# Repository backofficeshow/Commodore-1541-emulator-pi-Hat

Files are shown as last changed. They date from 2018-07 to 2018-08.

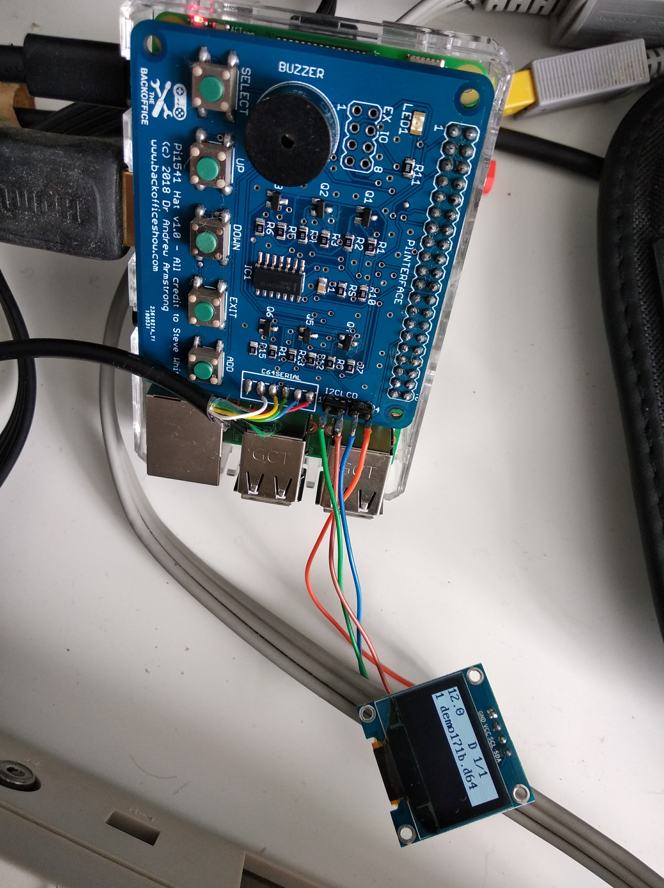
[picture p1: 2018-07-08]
Rob Taylor Test of V1.jpg

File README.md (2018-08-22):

# Commodore-1541-emulator-pi-Hat
Raspberry Pi Hat for Steve White's Excellent software emulated 1541

Feel free to use this design for your own personal use. If you want to use it in your commercial design please contact me first, this is a community supported design and to play fair its nice to be asked!

Steve White's excellent project:
https://cbm-pi1541.firebaseapp.com/

The video stream about this design:
https://youtu.be/9ZHAoGowLNE

The video stream about the build:
https://www.youtube.com/watch?v=_NtLqHfJCsg

Backofficeshow links:
https://www.youtube.com/backofficeshow
https://www.backofficeshow.com

Please feel free to ping me on twitter: @backofficeshow
or be a real superstar and consider buying me a coffee via Patreon: https://www.patreon.com/BackofficeShow

TODO:

Replace level shifting components with integrated circuit: http://www.ti.com/lit/ds/symlink/txb0108.pdf

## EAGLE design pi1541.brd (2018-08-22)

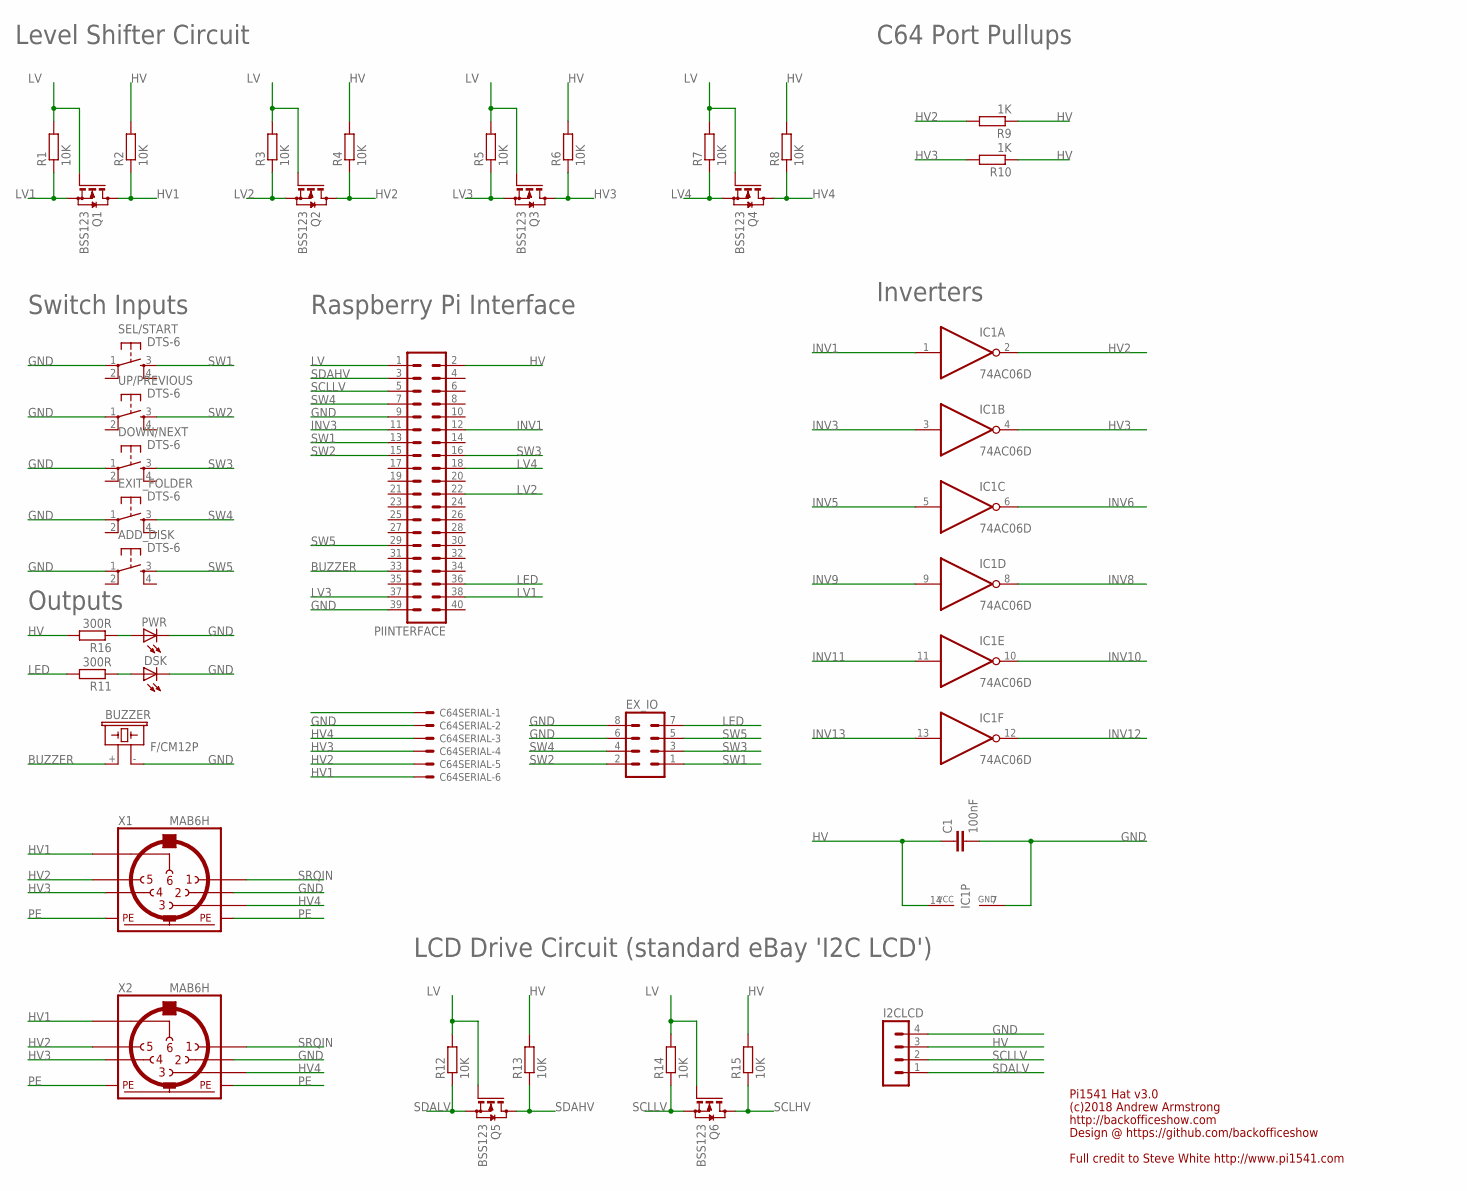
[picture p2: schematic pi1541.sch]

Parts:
ADD_DISK: DTS-6
BUZZER: F/CM12P
C1: 100nF; C0805
C64SERIAL: 22-23-2061
DOWN/NEXT: DTS-6
DSK: LEDCHIPLED_0805; CHIPLED_0805
EXIT_FOLDER: DTS-6
EX_IO: MA04-2
I2CLCD: MA04-1
IC1: 74AC06D; SO14
PIINTERFACE: MA20-2
PWR: LEDCHIPLED_0805; CHIPLED_0805
Q1, Q2, Q3, Q4, Q5, Q6: BSS123; SOT23
R1, R2, R3, R4, R5, R6, R7, R8, R12, R13, R14, R15: 10K; R0805
R9, R10: 1K; R0805
R11, R16: 300R; R0805
SEL/START: DTS-6
UP/PREVIOUS: DTS-6
X1, X2: MAB6H

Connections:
BUZZER: BUZZER.+ (1), PIINTERFACE.33
GND: ADD_DISK.1, BUZZER.- (2), C1.2, C64SERIAL.2, DOWN/NEXT.1, DSK.C, EXIT_FOLDER.1, EX_IO.6, EX_IO.8, I2CLCD.4, IC1.7 (GND), PIINTERFACE.9, PIINTERFACE.39, PWR.C, SEL/START.1, UP/PREVIOUS.1, X1.2, X2.2
HV: C1.1, I2CLCD.3, IC1.14 (VCC), PIINTERFACE.2, R2.2, R4.2, R6.2, R8.2, R9.1, R10.1, R13.2, R15.2, R16.2
HV1: C64SERIAL.6, Q1.3 (D), R2.1, X1.6, X2.6
HV2: C64SERIAL.5, IC1.2 (O), Q2.3 (D), R4.1, R9.2, X1.5, X2.5
HV3: C64SERIAL.4, IC1.4 (O), Q3.3 (D), R6.1, R10.2, X1.4, X2.4
HV4: C64SERIAL.3, Q4.3 (D), R8.1, X1.3, X2.3
INV1: IC1.1 (I), PIINTERFACE.12
INV3: IC1.3 (I), PIINTERFACE.11
INV5: IC1.5 (I)
INV6: IC1.6 (O)
INV8: IC1.8 (O)
INV9: IC1.9 (I)
INV10: IC1.10 (O)
INV11: IC1.11 (I)
INV12: IC1.12 (O)
INV13: IC1.13 (I)
LED: EX_IO.7, PIINTERFACE.36, R11.2
LV: PIINTERFACE.1, Q1.1 (G), Q2.1 (G), Q3.1 (G), Q4.1 (G), Q5.1 (G), Q6.1 (G), R1.2, R3.2, R5.2, R7.2, R12.2, R14.2
LV1: PIINTERFACE.38, Q1.2 (S), R1.1
LV2: PIINTERFACE.22, Q2.2 (S), R3.1
LV3: PIINTERFACE.37, Q3.2 (S), R5.1
LV4: PIINTERFACE.18, Q4.2 (S), R7.1
unnamed: DSK.A, R11.1
unnamed: PWR.A, R16.1
PE: X1.PE, X1.PE@ (PE), X2.PE, X2.PE@ (PE)
SCLHV: Q6.3 (D), R15.1
SCLLV: I2CLCD.2, PIINTERFACE.5, Q6.2 (S), R14.1
SDAHV: PIINTERFACE.3, Q5.3 (D), R13.1
SDALV: I2CLCD.1, Q5.2 (S), R12.1
SRQIN: X1.1, X2.1
SW1: EX_IO.1, PIINTERFACE.13, SEL/START.3
SW2: EX_IO.2, PIINTERFACE.15, UP/PREVIOUS.3
SW3: DOWN/NEXT.3, EX_IO.3, PIINTERFACE.16
SW4: EXIT_FOLDER.3, EX_IO.4, PIINTERFACE.7
SW5: ADD_DISK.3, EX_IO.5, PIINTERFACE.29

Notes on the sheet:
Level Shifter Circuit
Inverters
C64 Port Pullups
Raspberry Pi Interface
Switch Inputs
LCD Drive Circuit (standard eBay 'I2C LCD')
Full credit to Steve White http://www.pi1541.com
Pi1541 Hat v3.0
(c)2018 Andrew Armstrong
http://backofficeshow.com
Design @ https://github.com/backofficeshow
Outputs

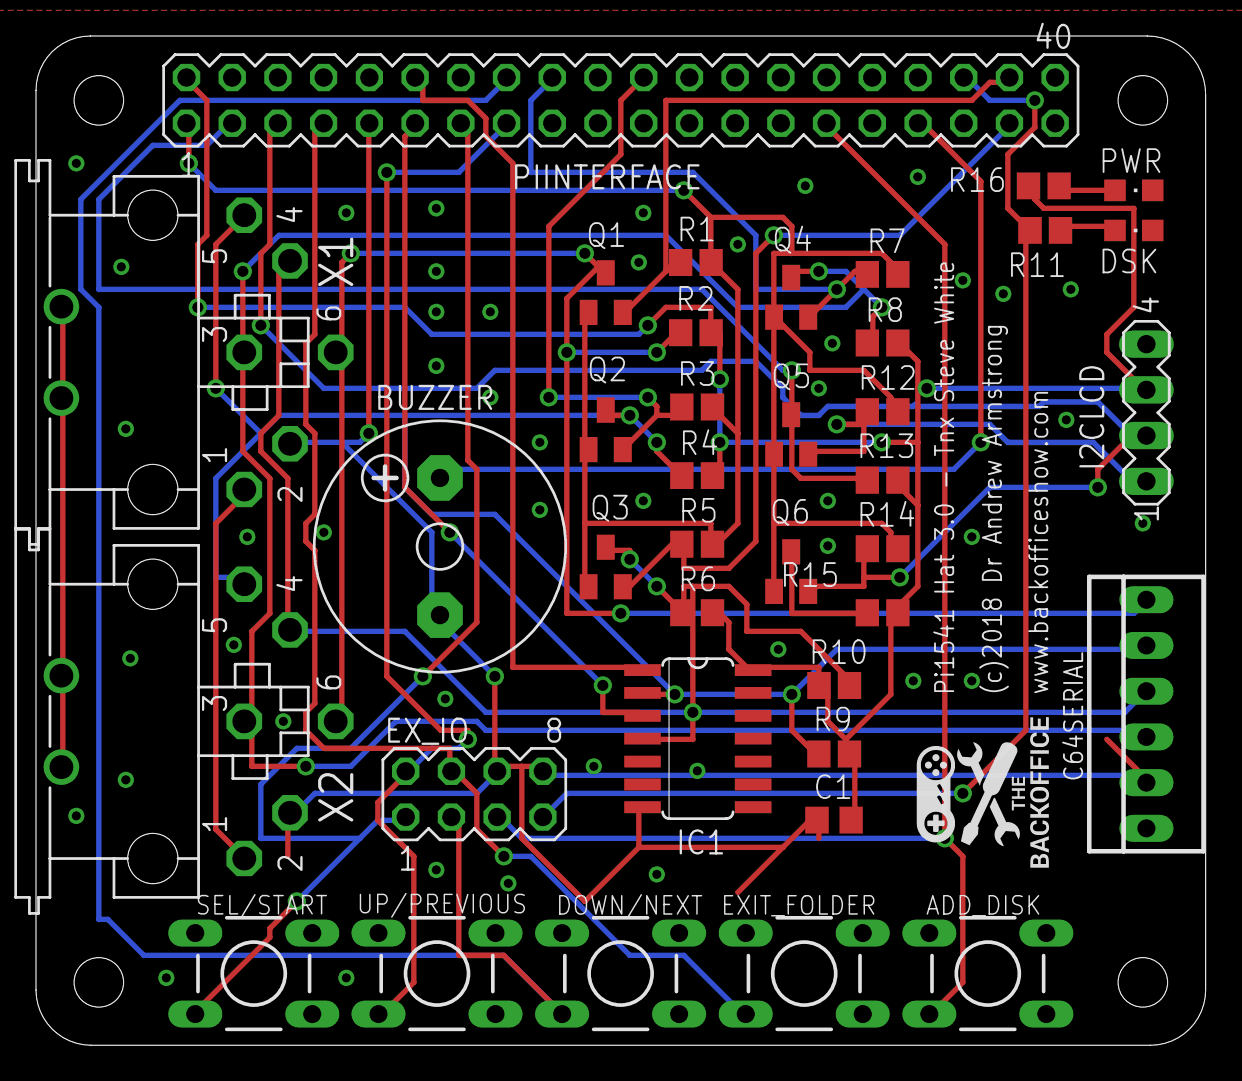
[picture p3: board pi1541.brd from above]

Board: 2 copper layers, 65.0 x 56.1 mm, 38 parts (0 on the bottom side), 28 nets.

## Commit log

2018-05-28 Updated Footprint for Alpha Print
    Ready to have prototype made now and see what happens!
    Mainly footprint adjusted to Pi3 spacing
    [pi1541.brd, pi1541.sch]
2018-07-08 Version 2
    Now with additional serial interface ports for those wishing to use a DIN interconnect. Everything else remains the same electrically as tested already by Rob Taylor.
    [pi1541.brd, pi1541.sch]
2018-07-08 Screenshot of the V2 PCB
2018-07-08 Image of the V1 Board
    Kindly Manufactured by Rob Taylor for testing.
2018-07-08 Corrected via tenting
    [pi1541.brd]
2018-08-20 Bill of materials export
2018-08-22 Updates
    Added Power LED
    Modified OLED Header for more common boards available
    Modified Tactile switches to through hole variety to ease construction
    [pi1541.brd, pi1541.sch]

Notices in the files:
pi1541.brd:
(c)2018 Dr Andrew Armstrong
